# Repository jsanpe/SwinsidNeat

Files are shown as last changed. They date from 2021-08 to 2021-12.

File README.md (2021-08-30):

# Nano SwinSID Neat

Yet another PCB layout of the nano SwinSID focusing on aesthetics

*Note: The design was modified and the new PCB has not been fully tested. I will remove this note when I can get some PCBs with this new layout and test them myself.*

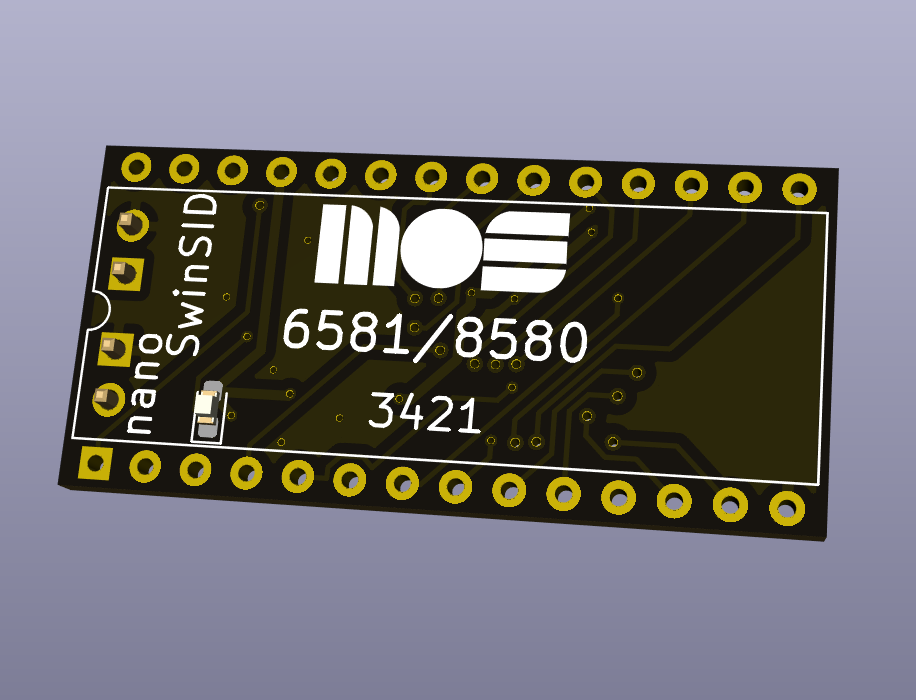
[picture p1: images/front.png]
Nano SwinSID Neat


## What is this repo about?

A kicad implementation of the Swinsid Nano. Based on the `nano SwinSID b` design by Tolaemon (http://tolaemon.com/nss/), this implementation preserves the schematic but introduces changes in the PCB layout:
- All components are placed on the bottom layer: the goal is to leave the top layer component free and use the silkscreen to mimic the MOS 6581 logo. So, this new layout has aesthetic purposes only.
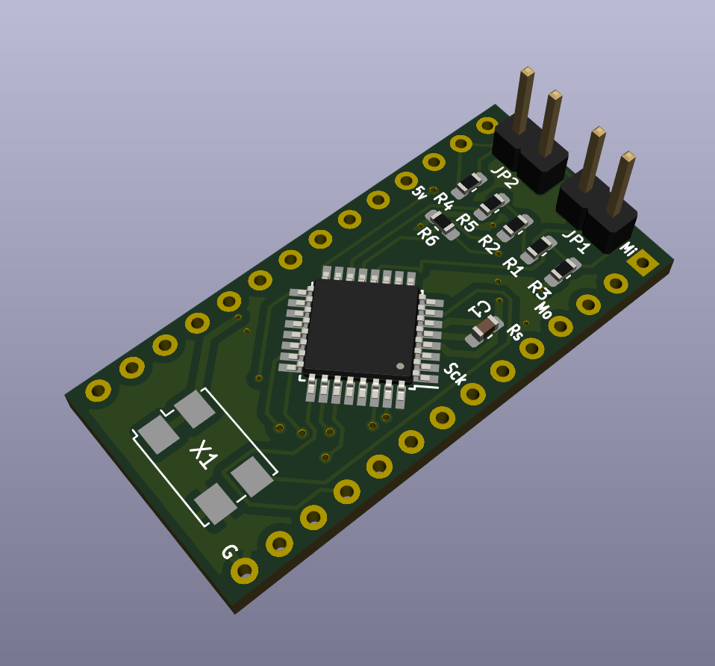
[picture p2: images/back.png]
SwinSID Bottom Layer


- The ICSP header is now gone ~~optional~~: Some of the pins on the side have been repurposed to program the ATMega without the need to add an additional 2x3 header, which contributes to a cleaner top. The required connections are marked in the PCB

| ICSP Pin | Swinsid Pin | Silkscreen Mark |
|---|---|---|
| 1 - Miso | Pin 1 |Mi|
| 2 - Vcc  | Pin 25 |5v|
| 3 - Sck  | Pin 7 |Sck|
| 4 - Mosi | Pin 4 |Mo|
| 5 - Reset| Pin 5 |Rs|
| 6 - Gnd  | Pin 14| G|

- The LED is placed on the top layer, mostly for visibility reasons (in daylight conditions it is easier to spot the led to verify power is reaching the swinsid). However, the led is fully optional allowing the top layer to only have the silkscreen.

Other than these two minor changes, the design is the exact same as Tolaemon's, so all credits go to him and, of course, the original creator of the Swinsid Nano (x1541 ~ http://www.nightfallcrew.com/27/02/2011/nanoswinsid-pcb-by-x1541/) and its predecessors.

## BOM
| Comment	| Designator |	Footprint |
|---|---|---|
| 100n	| C1 |	SMD 0603 |
| LED	  |  D1|	LED_0603 |
|Conn_PIC_ICSP_ICD|	J1	| PinHeader_2x03_P2.54mm_Vertical |
|Jumper |	JP1,JP2	| PinHeader_1x02_P2.54mm_Vertical |
|2k2	|R1	|SMD 0603|
|4k7	|R3	|SMD 0603|
|1k	|R2,R4	|SMD 0603|
|240k	|R5	|SMD 0603|
|330	|R6	|SMD 0603|
|ATmega88PA-AU	|U1	|TQFP-32_7x7mm_P0.8mm|
|SG-7050CAN 32Mhz|	X1	|Crystal_SMD_7050-4Pin_7.0x5.0mm|

## Jumpers
- JP1: Selects emulation mode. Leave open for 8580, and close for 6581
- JP2: Selects output voltage. Leave open for mainboards designed for 6581 (this resistor is already in the mainboard), and close for mainboards designed for 8580.

My personal preference is to permanently solder the pads instead of placing a jumper for aesthetic reasons. Feel free to do otherwise.

## Firmware
Please refer to Toalemon's [guide](http://tolaemon.com/nss/) for additional information on available firmwares and how to flash them in the ATMega MPU.

## License
Given the incremental nature of this design, the original licenses of the Nano SwinSID and Nano SwinSIDb apply to this repo. I have not been able to clearly identify what licenses these original designs have, so in the absence of any additional info the current repo has been released under a MIT license. Please contanct me or open an issue in github if you have additional information about licensing that should be included.

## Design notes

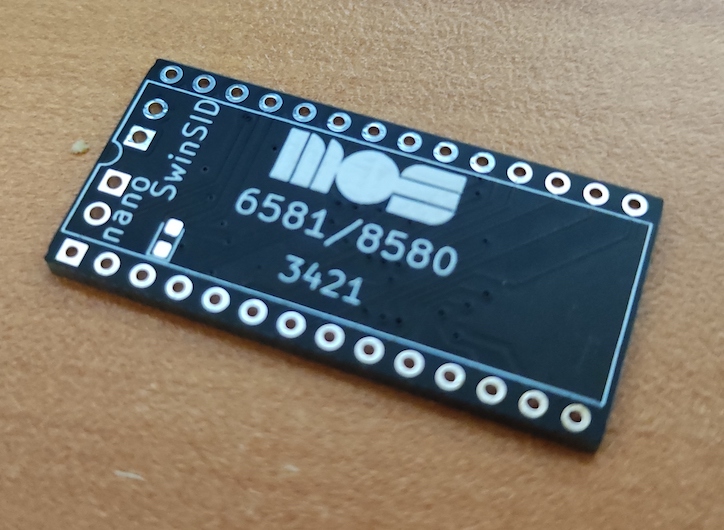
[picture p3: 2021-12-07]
images/swinsidneat.jpg

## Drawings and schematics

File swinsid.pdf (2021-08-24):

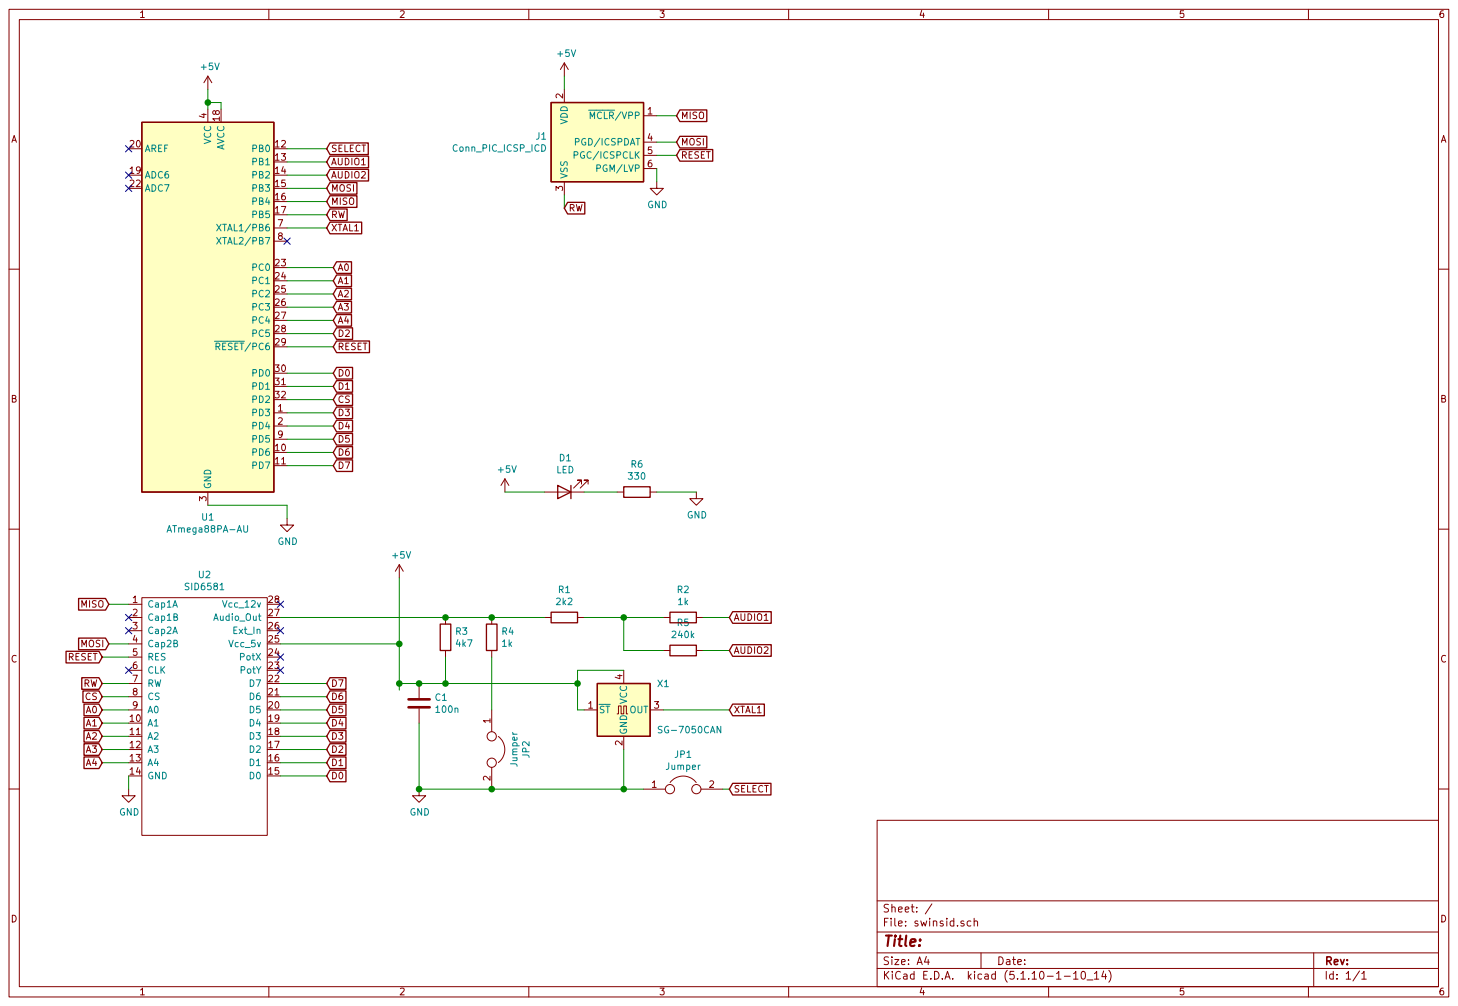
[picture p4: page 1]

Id: 1/1 Title: File: swinsid.sch Sheet: /

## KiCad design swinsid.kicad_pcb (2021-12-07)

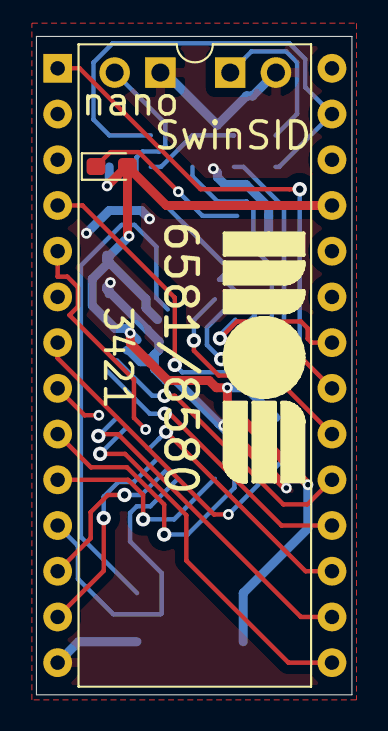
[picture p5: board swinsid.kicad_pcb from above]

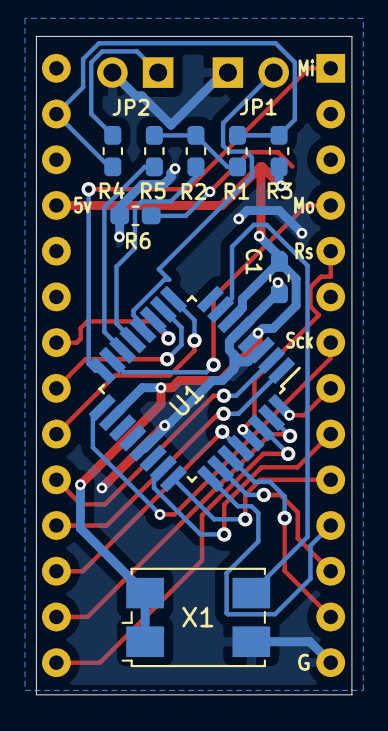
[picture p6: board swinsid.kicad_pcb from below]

Board: 2 copper layers, 17.5 x 36.6 mm, 13 parts (11 on the bottom side), 28 nets.

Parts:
C1: 100n; C_0603_1608Metric_Pad1.05x0.95mm_HandSolder
D1: LED; LED_0603_1608Metric_Pad1.05x0.95mm_HandSolder
JP1, JP2: Jumper; PinHeader_1x02_P2.54mm_Vertical
R1: 2k2; R_0603_1608Metric_Pad1.05x0.95mm_HandSolder
R2, R4: 1k; R_0603_1608Metric_Pad1.05x0.95mm_HandSolder
R3: 4k7; R_0603_1608Metric_Pad1.05x0.95mm_HandSolder
R5: 240k; R_0603_1608Metric_Pad1.05x0.95mm_HandSolder
R6: 330; R_0603_1608Metric_Pad1.05x0.95mm_HandSolder
U1: ATmega88PA-AU; TQFP-32_7x7mm_P0.8mm
U2: SID6581; DIP-28_W15.24mm
X1: SG-7050CAN; Crystal_SMD_7050-4Pin_7.0x5.0mm

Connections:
+5V: C1.1, D1.2, R3.2, U1.4, U1.6, U1.18, U2.25, X1.1, X1.4
A0: U1.23, U2.9
A1: U1.24, U2.10
A2: U1.25, U2.11
A3: U1.26, U2.12
A4: U1.27, U2.13
AUDIO1: R2.2, U1.13
AUDIO2: R5.2, U1.14
CS: U1.32, U2.8
D0: U1.30, U2.15
D1: U1.31, U2.16
D2: U1.28, U2.17
D3: U1.1, U2.18
D4: U1.2, U2.19
D5: U1.9, U2.20
D6: U1.10, U2.21
D7: U1.11, U2.22
GND: C1.2, JP1.1, JP2.2, R6.2, U1.3, U1.5, U1.21, U2.14, X1.2
MISO: U1.16, U2.1
MOSI: U1.15, U2.4
unnamed: D1.1, R6.1
unnamed: JP2.1, R4.2
unnamed: R1.1, R3.1, R4.1, U2.27
unnamed: R1.2, R2.1, R5.1
RESET: U1.29, U2.5
RW: U1.17, U2.7
SELECT: JP1.2, U1.12
XTAL1: U1.7, X1.3

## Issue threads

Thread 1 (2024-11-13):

Garbage noise and beeps

Aisflou, 2024-11-13:
Hell, i just order some pcbs to make a couple of this replacements as your design looks so much more neat :D all went well, i programmed the ics without problem. The first unit that i soldered went to a friend, with an ASSY NO. 250407 board, as the tittle says, he gets noises and beeps, not reasembling to any correct sound, his sid works mostly well, so, not a problem of the mainboard it seems, he tried changing the jumpers, with no luck, same noises... he used kungfuflash and rad to make the test, same results... do you think of something we can test maybe? Thanks anyway for the project as it looks so great indeed. Hope we can found the problem and be able to fix it! :D Greetings!

jsanpe, 2024-11-20:
Hi there. Not sure what could be goin on to be honest. In my own testing I got good quality sound out of the board, so my guess is that something went wrong during the assembly of the board. Check the resistor values and connectivity, note that the output signal is composed by transforming PWM pulses into the audio wave through a network of resistors. If something is wrong in this network, the the output can be affected. Another part to check is the crystal, check that it is outputing the right frequency.

There's really nothing new to this design other that the aesthetics, it's the well tested Swinsid. My guess is that there's a faulty part or a bad connection going on.

Aisflou, 2024-11-21:
Thanks, i will make another one and test it on my own c64 to see it ifs just the unit i sent to my friend, probably thats the problem :D

Aisflou, 2024-12-30:
Hello, im happy to soy that i am a total stupid, forgot to configure the fuses correctly, that was the issue :( sorry for bother and thanks for all! You can add that the desing functions well as expected. Greetings!

Closed 2024-12-30.

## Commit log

2021-08-24 Initial Release
    [swinsid.kicad_pcb, swinsid.sch]
2021-08-29 New layout without C logo Remove ICSP 2x3 header for better layout Rotate MCU for better layout
    [swinsid.kicad_pcb]
2021-08-29 Update gerbers
2021-12-07 Updated swinsid image
    [swinsid.kicad_pcb, swinsid.sch]
